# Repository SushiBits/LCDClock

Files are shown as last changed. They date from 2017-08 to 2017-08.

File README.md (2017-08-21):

# SushiBits LCD Clock

Novelty clock with connectivity.

## Introduction & Goal

I always needed a clock with climate sensors in my room, but despite the cheap
ones available (including the flippy one from IKEA which my mom uses in the
kitchen) I never got around buying one. A while ago I set up a GPS-based Stratum
1 NTP server using one of my spare Raspberry Pi's. Now how about building a
clock, with not only climate sensors, but also can receive time over NTP?

The clock needs to sit in my bookshelf. It joins my home network to gain access
to the NTP server (or anyone else's over Internet) to pull the time. And maybe
it can collect the report the collected climate data to a server.

Thus, here is the design goals:

*	Temperature and humidity sensors.
*	Have a display to show the current date, time, temperature and humidity.
*	Battery-powered device.
*	Wi-Fi capable.

## Hardware

I am aware of the ESP8266-based systems, however I cannot keep the wireless on
all the time in order not to drain the batteries too quickly. Instead a separate
microcontroller is used for the system operation, and the ESP8266 module is on
only during the NTP time sync or batched data reporting process.

The overall hardware includes:

*	Processor: STM32F103CBT6 or STM32F303CCT6
*	Climate Sensor: DHT12
*	Wireless Module: ESP-12E ESP8266 based module
*	Display: 16x2 HD44780-compatible LCD
*	Connectivity: USB for communication and charging, Wi-Fi, Serial and JTAG

## License

This is [open source hardware](http://www.oshwa.org/), licensed under the
[3-clause BSD license](LICENSE.md).

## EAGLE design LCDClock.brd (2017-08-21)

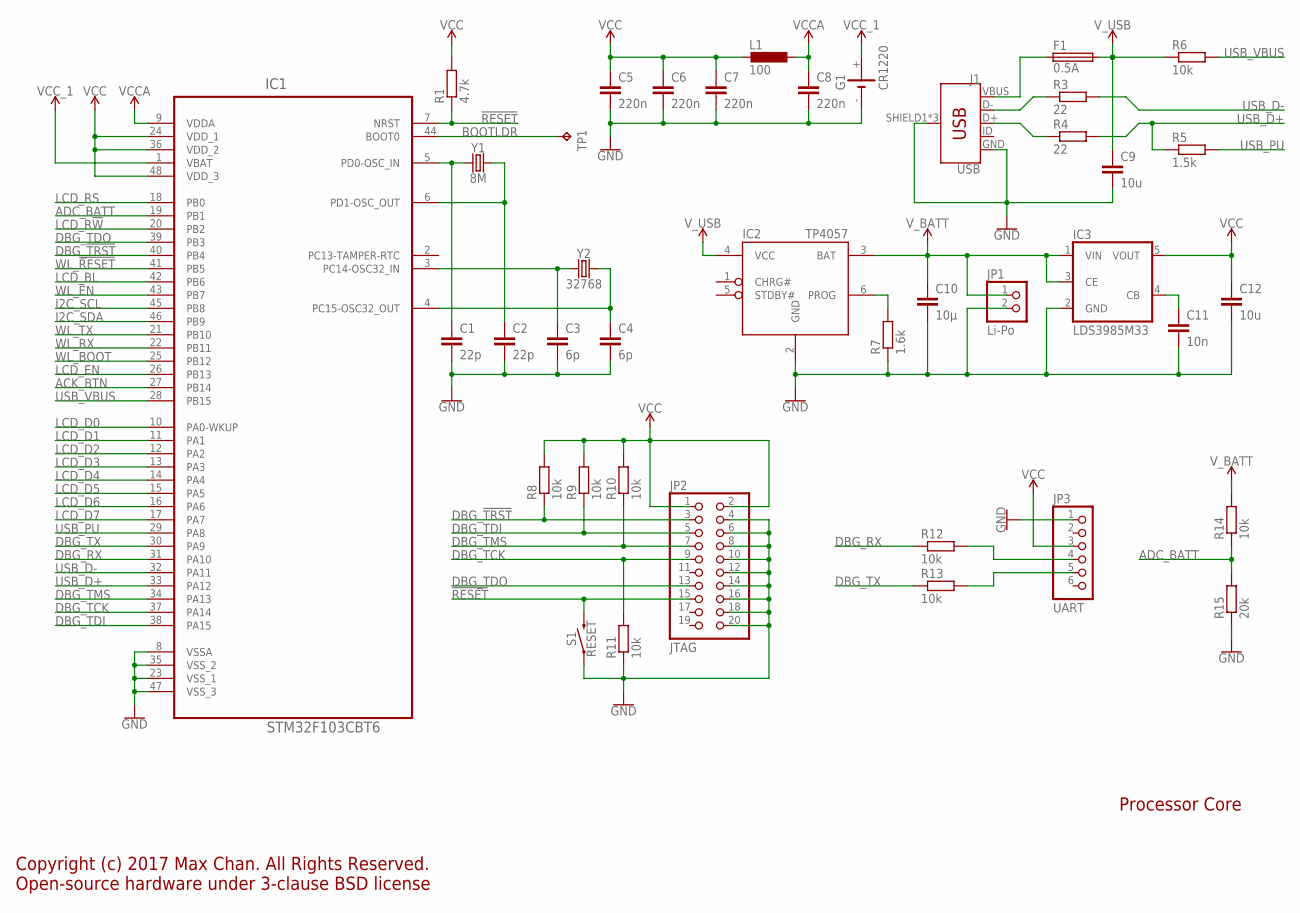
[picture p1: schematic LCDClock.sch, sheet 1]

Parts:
C1, C2: 22p; C0603
C3, C4: 6p; C0603
C5, C6, C7, C8: 220n; C0603
C9, C12: 10u; C0805
C10: 10µ; C0805
C11: 10n; C0603
F1: 0.5A; R1206
G1: CR1220; CH291-1220LF
IC1: STM32F103CBT6; QFP50P900X900X160-48N
IC2: TP4057; SOT23-6
IC3: LDS3985M33; SOT25
J1: USB; USB-B-MICRO-SMD
JP1: Li-Po; 1X02
JP2: JTAG; 2X10/90
JP3: UART; 1X06/90
L1: 100; L2012C
R1: 4.7k; R0603
R3, R4: 22; R0603
R5: 1.5k; R0603
R6, R8, R9, R10, R11, R12, R13, R14: 10k; R0603
R7: 1.6k; R0603
R15: 20k; R0603
S1: RESET; TACTILE_SWITCH_SMD_6.0X3.5MM
TP1: TPTP10R; TP10R
Y1: 8M; CRYSTAL-SMD-5X3.2-4PAD
Y2: 32768; CRYSTAL-SMD-3.2X1.5MM

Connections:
!RESET: IC1.7 (NRST), JP2.15, R1.1, S1.2
ACK_BTN: IC1.27 (PB14); also elsewhere on the board
ADC_BATT: IC1.19 (PB1), R14.1, R15.2
BATT_PROG: IC2.6 (PROG), R7.2
BOOTLDR: IC1.44 (BOOT0), TP1.TP
DBGRX: JP3.4, R12.2
DBGTX: JP3.5, R13.2
DBG_!TRST: IC1.40 (PB4), JP2.3, R8.1
DBG_RX: IC1.31 (PA10), R12.1
DBG_TCK: IC1.37 (PA14), JP2.9, R11.2
DBG_TDI: IC1.38 (PA15), JP2.5, R9.1
DBG_TDO: IC1.39 (PB3), JP2.13
DBG_TMS: IC1.34 (PA13), JP2.7, R10.1
DBG_TX: IC1.30 (PA9), R13.1
GND: C1.2, C2.2, C3.2, C4.2, C5.2, C6.2, C7.2, C8.2, C9.2, C10.2, C11.2, C12.2, G1.-, IC1.8 (VSSA), IC1.23 (VSS_1), IC1.35 (VSS_2), IC1.47 (VSS_3), IC2.2 (GND), IC3.2 (GND), J1.GND, J1.SHIELD1 (SHIELD), J1.SHIELD2 (SHIELD), J1.SHIELD3 (SHIELD), JP1.2, JP2.4, JP2.6, JP2.8, JP2.10, JP2.12, JP2.14, JP2.16, JP2.18, JP2.20, JP3.1, R7.1, R11.1, R15.1, S1.1; also elsewhere on the board
HSE_IN: C1.1, IC1.5 (PD0-OSC_IN), Y1.1
HSE_OUT: C2.1, IC1.6 (PD1-OSC_OUT), Y1.3 (2)
I2C_SCL: IC1.45 (PB8); also elsewhere on the board
I2C_SDA: IC1.46 (PB9); also elsewhere on the board
LCD_BL: IC1.42 (PB6); also elsewhere on the board
LCD_D0: IC1.10 (PA0-WKUP); also elsewhere on the board
LCD_D1: IC1.11 (PA1); also elsewhere on the board
LCD_D2: IC1.12 (PA2); also elsewhere on the board
LCD_D3: IC1.13 (PA3); also elsewhere on the board
LCD_D4: IC1.14 (PA4); also elsewhere on the board
LCD_D5: IC1.15 (PA5); also elsewhere on the board
LCD_D6: IC1.16 (PA6); also elsewhere on the board
LCD_D7: IC1.17 (PA7); also elsewhere on the board
LCD_EN: IC1.26 (PB13); also elsewhere on the board
LCD_R!W: IC1.20 (PB2); also elsewhere on the board
LCD_RS: IC1.18 (PB0); also elsewhere on the board
LSE_IN: C3.1, IC1.3 (PC14-OSC32_IN), Y2.P$1 (1)
LSE_OUT: C4.1, IC1.4 (PC15-OSC32_OUT), Y2.P$2 (2)
UD+: J1.D+, R4.1
UD-: J1.D-, R3.1
USB_D+: IC1.33 (PA12), R4.2, R5.1
USB_D-: IC1.32 (PA11), R3.2
USB_PU: IC1.29 (PA8), R5.2
USB_VBUS: IC1.28 (PB15), R6.2
VBUS: F1.1, J1.VBUS
VCC: C5.1, C6.1, C7.1, C12.1, IC1.24 (VDD_1), IC1.36 (VDD_2), IC1.48 (VDD_3), IC3.5 (VOUT), JP2.1, JP2.2, JP3.3, L1.2, R1.2, R8.2, R9.2, R10.2; also elsewhere on the board
VCCA: C8.1, IC1.9 (VDDA), L1.1
VCC_1: G1.+, IC1.1 (VBAT)
VCC_FILT: C11.1, IC3.4 (CB)
V_BATT: C10.1, IC2.3 (BAT), IC3.1 (VIN), IC3.3 (CE), JP1.1, R14.2; also elsewhere on the board
V_USB: C9.1, F1.2, IC2.4 (VCC), R6.1
WL_!RESET: IC1.41 (PB5); also elsewhere on the board
WL_BOOT: IC1.25 (PB12); also elsewhere on the board
WL_EN: IC1.43 (PB7); also elsewhere on the board
WL_RX: IC1.22 (PB11); also elsewhere on the board
WL_TX: IC1.21 (PB10); also elsewhere on the board

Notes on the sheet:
Copyright (c) 2017 Max Chan. All Rights Reserved. Open-source hardware under 3-clause BSD license
Processor Core

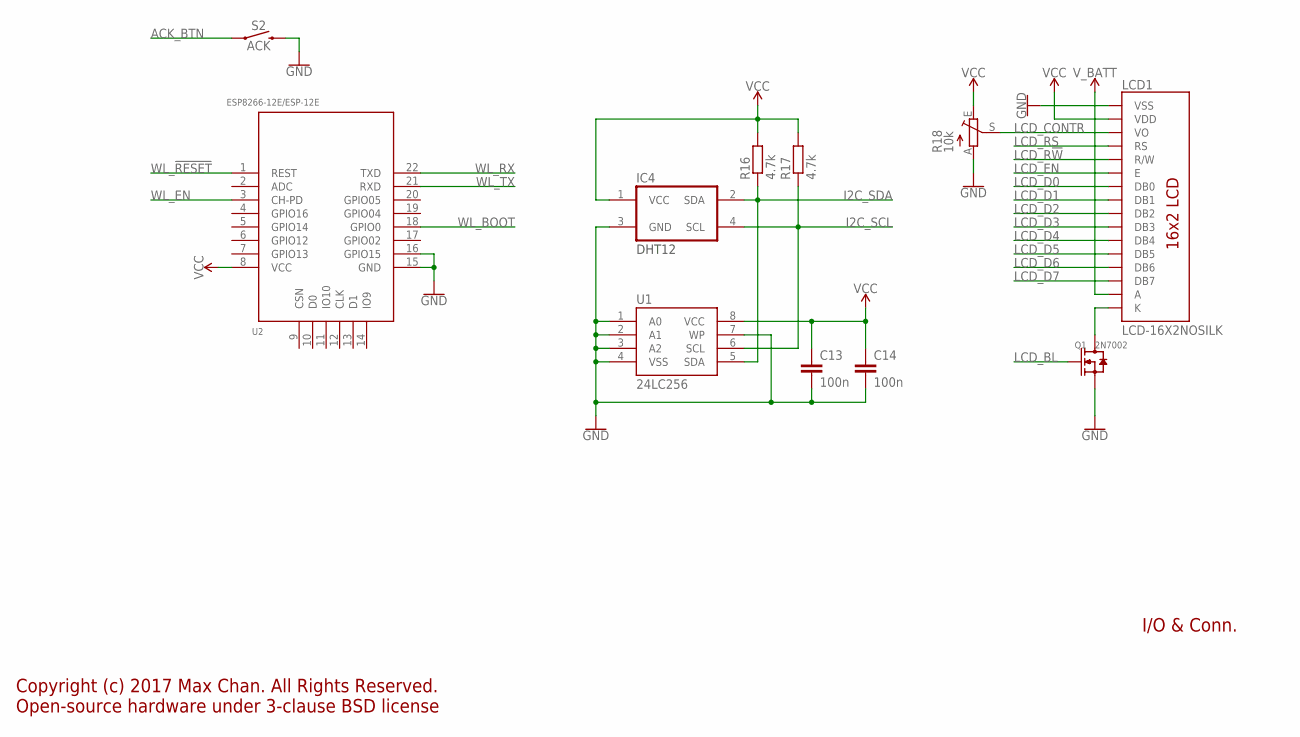
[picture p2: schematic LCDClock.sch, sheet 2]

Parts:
C13, C14: 100n; C0603
IC4: DHT12
LCD1: LCD-16X2NOSILK; LCD-16X2_NOSILK
Q1: 2N7002; SOT-23
R16, R17: 4.7k; R0603
R18: 10k; CA6V
S2: ACK; TACTILE_SWITCH_PTH_RIGHT_ANGLE_KIT
U1: 24LC256; SO08
U2: ESP8266-12E/ESP-12E; LGA22-2.0-24X16MM

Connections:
ACK_BTN: S2.1; also elsewhere on the board
GND: C13.2, C14.2, IC4.3 (GND), LCD1.1 (VSS), Q1.2 (S), R18.A, S2.2, U1.1 (A0), U1.2 (A1), U1.3 (A2), U1.4 (VSS), U1.7 (WP), U2.15 (GND), U2.16 (GPIO15); also elsewhere on the board
I2C_SCL: IC4.4 (SCL), R17.1, U1.6 (SCL); also elsewhere on the board
I2C_SDA: IC4.2 (SDA), R16.1, U1.5 (SDA); also elsewhere on the board
LCDBL: LCD1.16 (K), Q1.3 (D)
LCD_BL: Q1.1 (G); also elsewhere on the board
LCD_CONTR: LCD1.3 (VO), R18.S
LCD_D0: LCD1.7 (DB0); also elsewhere on the board
LCD_D1: LCD1.8 (DB1); also elsewhere on the board
LCD_D2: LCD1.9 (DB2); also elsewhere on the board
LCD_D3: LCD1.10 (DB3); also elsewhere on the board
LCD_D4: LCD1.11 (DB4); also elsewhere on the board
LCD_D5: LCD1.12 (DB5); also elsewhere on the board
LCD_D6: LCD1.13 (DB6); also elsewhere on the board
LCD_D7: LCD1.14 (DB7); also elsewhere on the board
LCD_EN: LCD1.6 (E); also elsewhere on the board
LCD_R!W: LCD1.5 (R/W); also elsewhere on the board
LCD_RS: LCD1.4 (RS); also elsewhere on the board
VCC: C13.1, C14.1, IC4.1 (VCC), LCD1.2 (VDD), R16.2, R17.2, R18.E, U1.8 (VCC), U2.8 (VCC); also elsewhere on the board
V_BATT: LCD1.15 (A); also elsewhere on the board
WL_!RESET: U2.1 (REST); also elsewhere on the board
WL_BOOT: U2.18 (GPIO0); also elsewhere on the board
WL_EN: U2.3 (CH-PD); also elsewhere on the board
WL_RX: U2.22 (TXD); also elsewhere on the board
WL_TX: U2.21 (RXD); also elsewhere on the board

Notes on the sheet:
Copyright (c) 2017 Max Chan. All Rights Reserved. Open-source hardware under 3-clause BSD license
I/O & Conn.

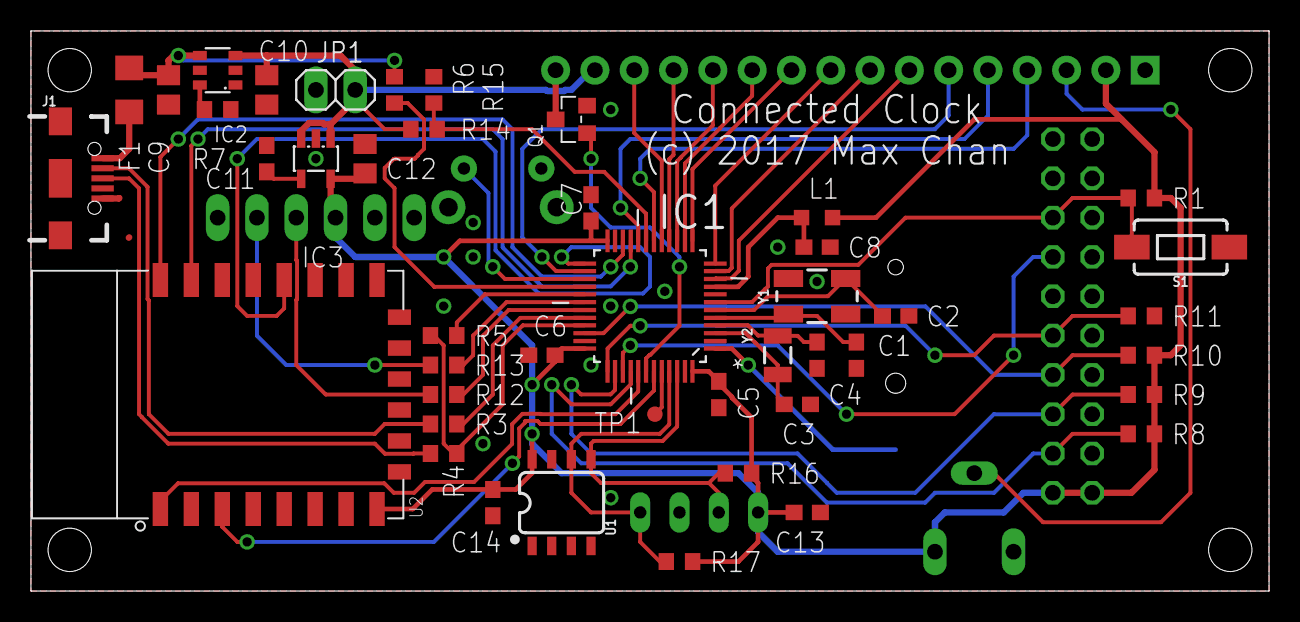
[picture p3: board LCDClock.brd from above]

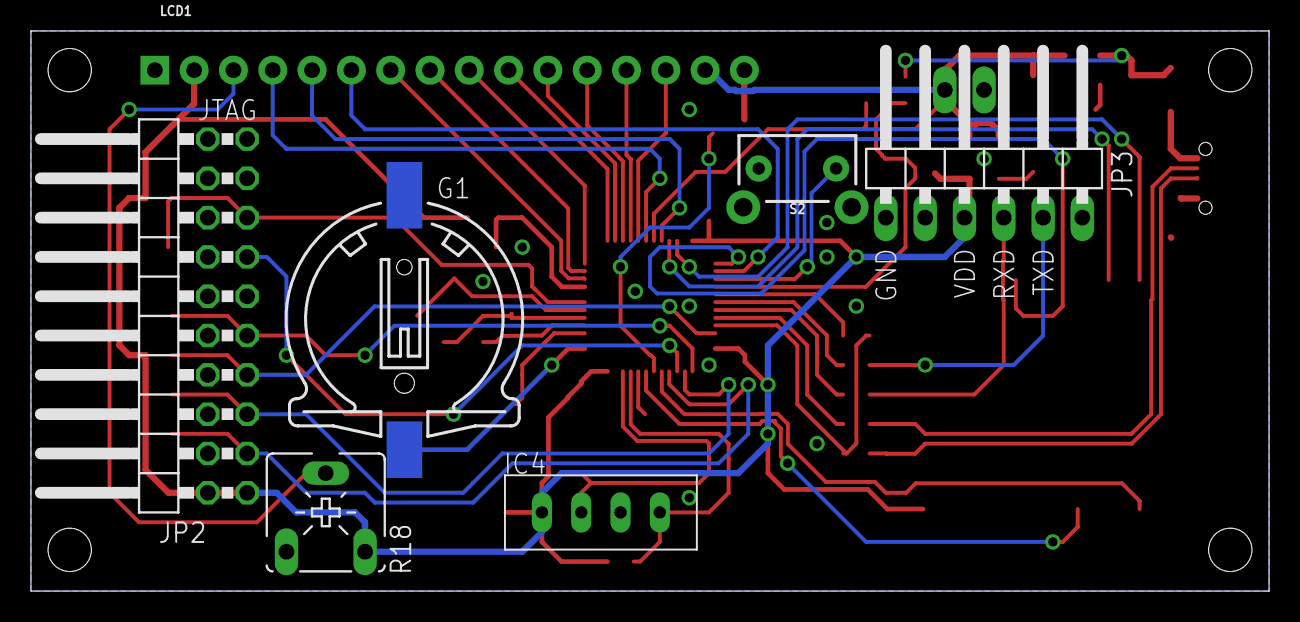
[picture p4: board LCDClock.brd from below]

Board: 2 copper layers, 80.0 x 36.2 mm, 51 parts (7 on the bottom side), 53 nets.

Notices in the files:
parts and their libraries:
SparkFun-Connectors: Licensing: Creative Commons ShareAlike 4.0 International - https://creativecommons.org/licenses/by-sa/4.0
